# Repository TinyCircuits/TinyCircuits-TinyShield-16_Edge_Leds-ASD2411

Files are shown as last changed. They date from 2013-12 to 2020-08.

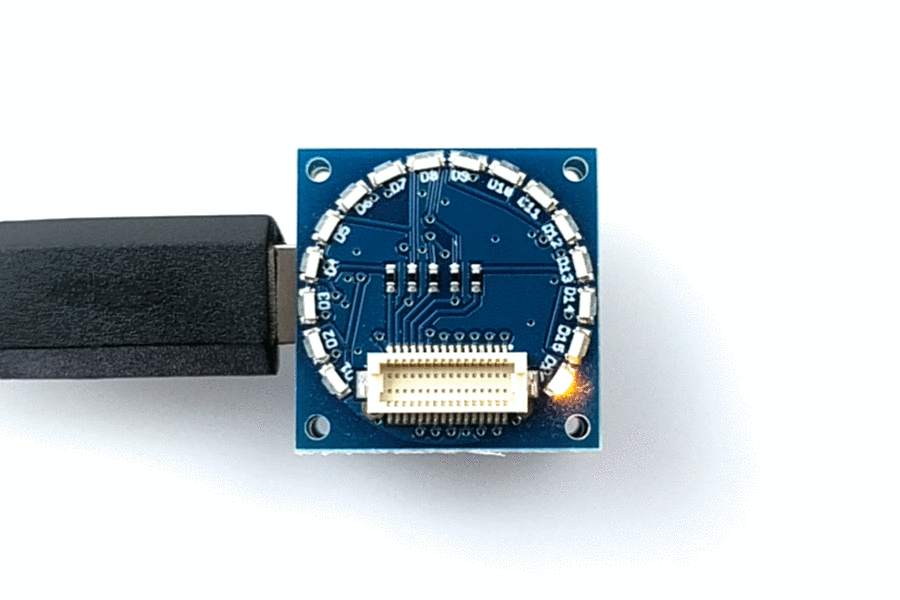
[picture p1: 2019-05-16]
images/ASD2411-R-LG-Tutorial-Animation-01.gif

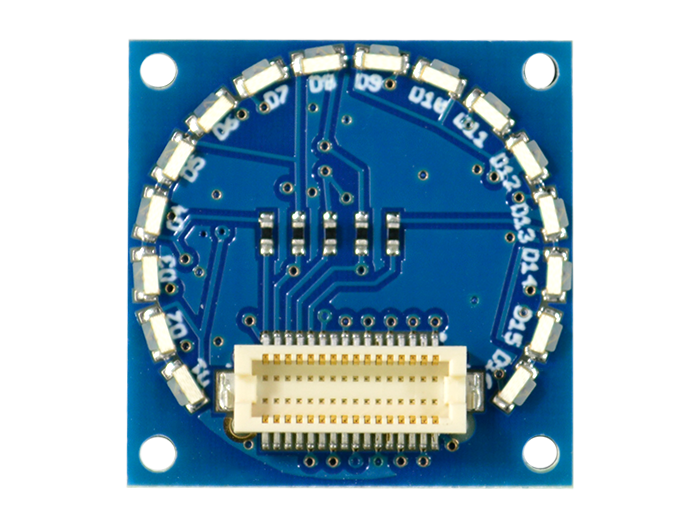
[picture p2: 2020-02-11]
images/ASD2411-R-LG-Tutorial-Image-01.png

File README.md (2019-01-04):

# TinyCircuits TinyShield 16 Edge LEDs
# ASD2411 Rev5

The design files are located under design_files/ for the TinyCircuits ASD2411 Rev 5 PCB.  This is a Tiny shield board (Square Version, 20mm x 20mm, or Circular 20mm diameter) that has a 16 LEDs around the border.

Format is in Cadsoft Eagle format - Eagle version 6.2 was used for the original design.

For more infomation on this, check out the product page at TinyCircuits.com: https://tinycircuits.com/collections/leds-displays/products/16-edge-led-tinyshield

# License:

Design by TinyCircuits.
All design files are released under the Creative Commons Attribution Share-Alike 3.0 License, see the following link for details: http://creativecommons.org/licenses/by-sa/3.0

All text above must be included in any redistribution or derived design

This project uses designs and concepts developed as part of the Arduino project and the LilyPad project.  The TinyCircuits design files themselves (schematics, PCB and libraries) are not directly derived from these works' design files and have been created new, however the concepts and basic architecture behind the TinyDuino and TinyLily products are derived and we thank the hard work of the organizations below for their contributions to open-source hardware:
  
Original Arduino Uno Design by Team Arduino

LilyPad Arduino Design by Leah Buechley and Sparkfun Electronics

Please support the open-source hardware community

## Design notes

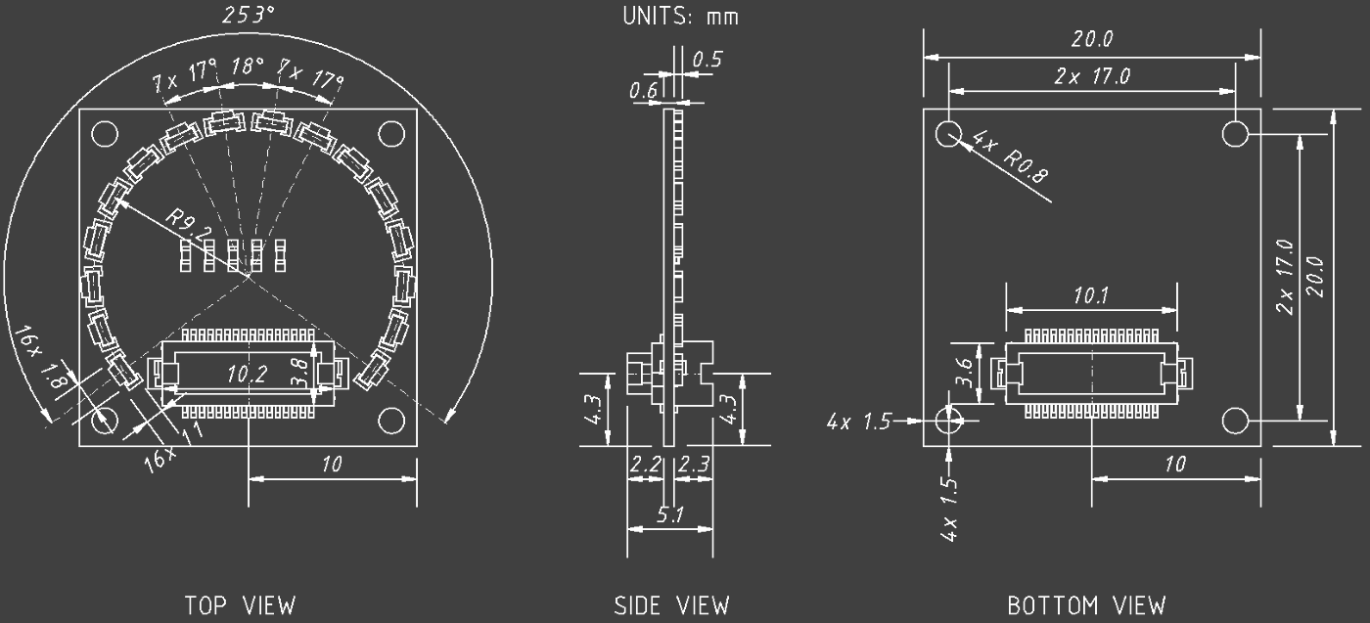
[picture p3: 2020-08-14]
cad/TinyShield_16_EDGE_LEDS_ASD2411-REV5_DETAILED_DRAWING_COMPACT-PNG.png

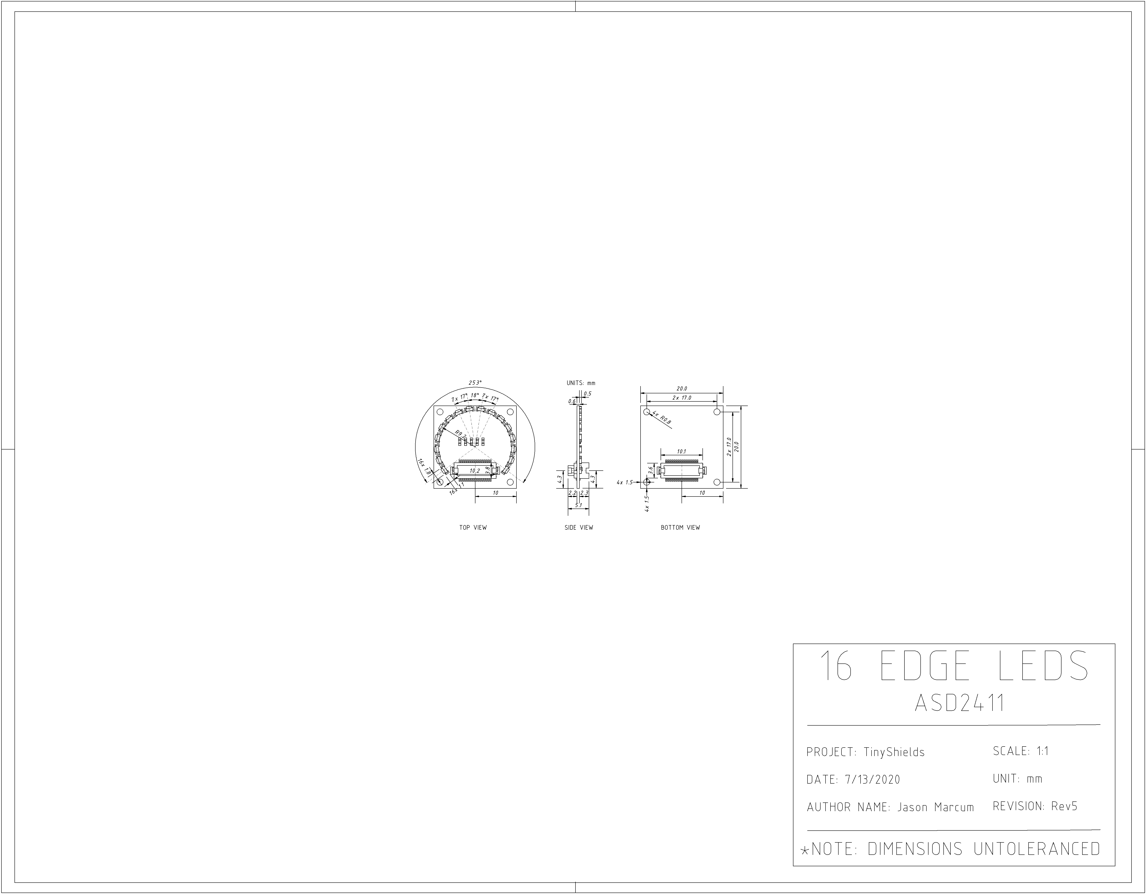
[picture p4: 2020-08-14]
cad/TinyShield_16_EDGE_LEDS_ASD2411_REV5-DETAILED_DRAWING-PNG.png

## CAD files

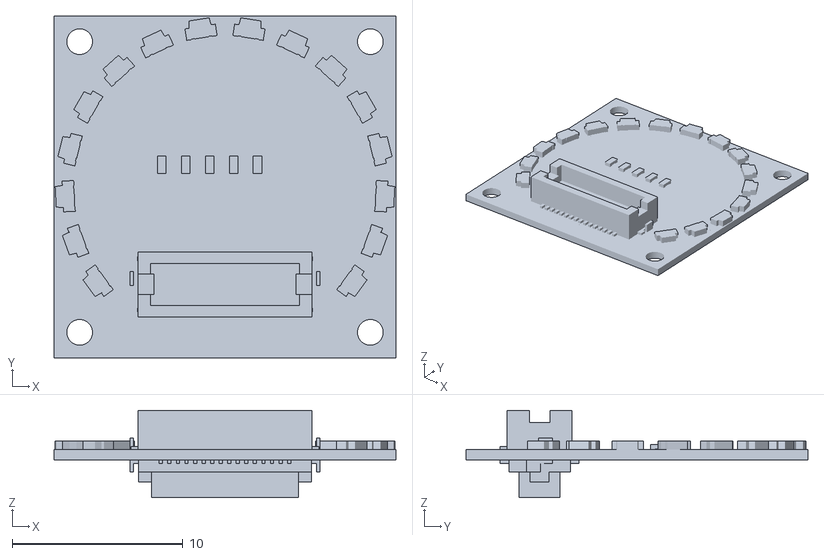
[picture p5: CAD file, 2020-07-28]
cad/TinyShield_16_EDGE_LEDS_ASD2411_REV5-STL.stl
20.0 x 20.0 x 5.10

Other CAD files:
cad/ TinyShield_16_EDGE_LEDS_ASD2411_REV5-DETAILED_DRAWING-DXF.dxf

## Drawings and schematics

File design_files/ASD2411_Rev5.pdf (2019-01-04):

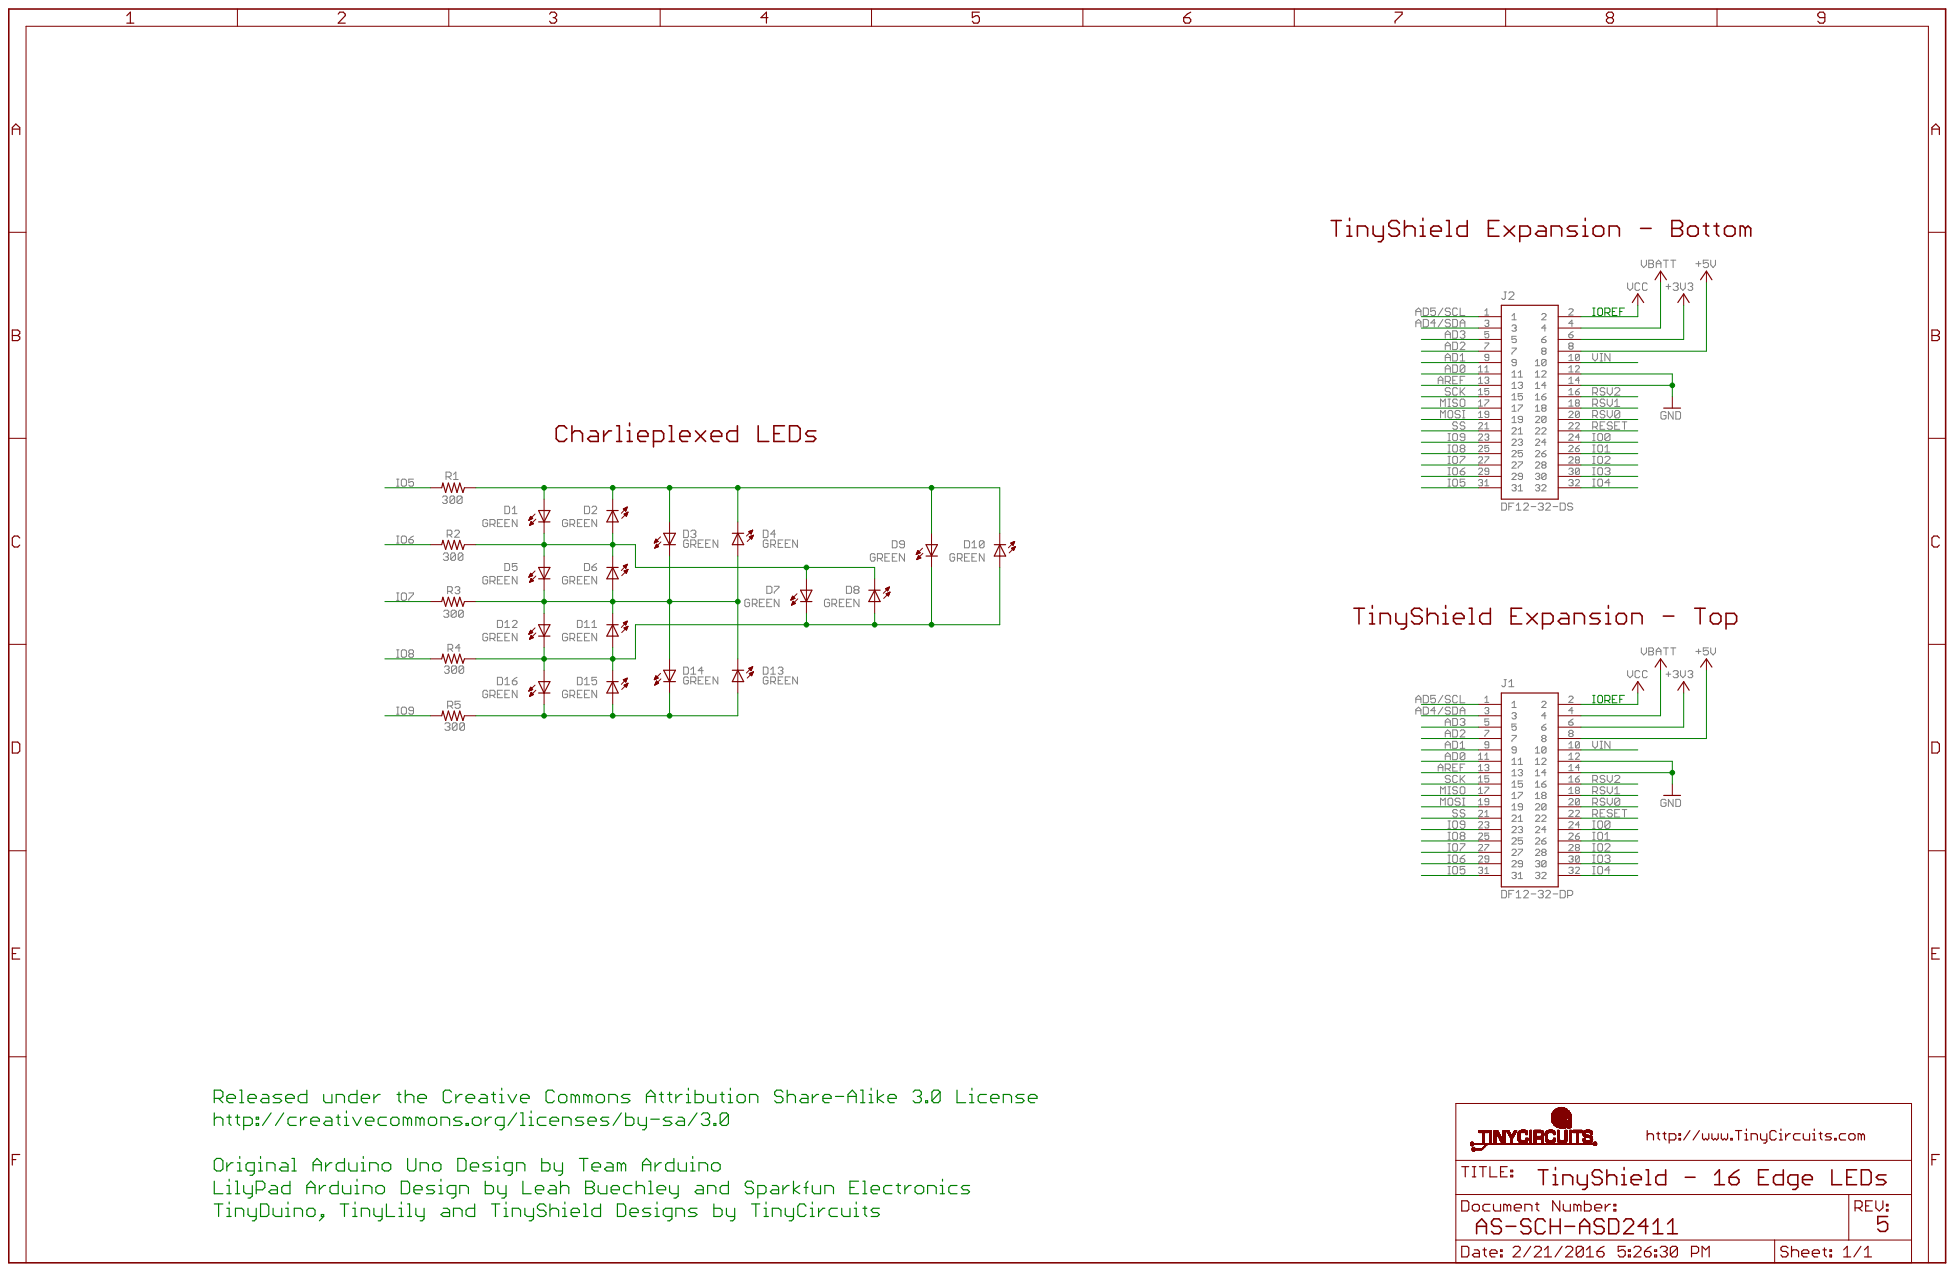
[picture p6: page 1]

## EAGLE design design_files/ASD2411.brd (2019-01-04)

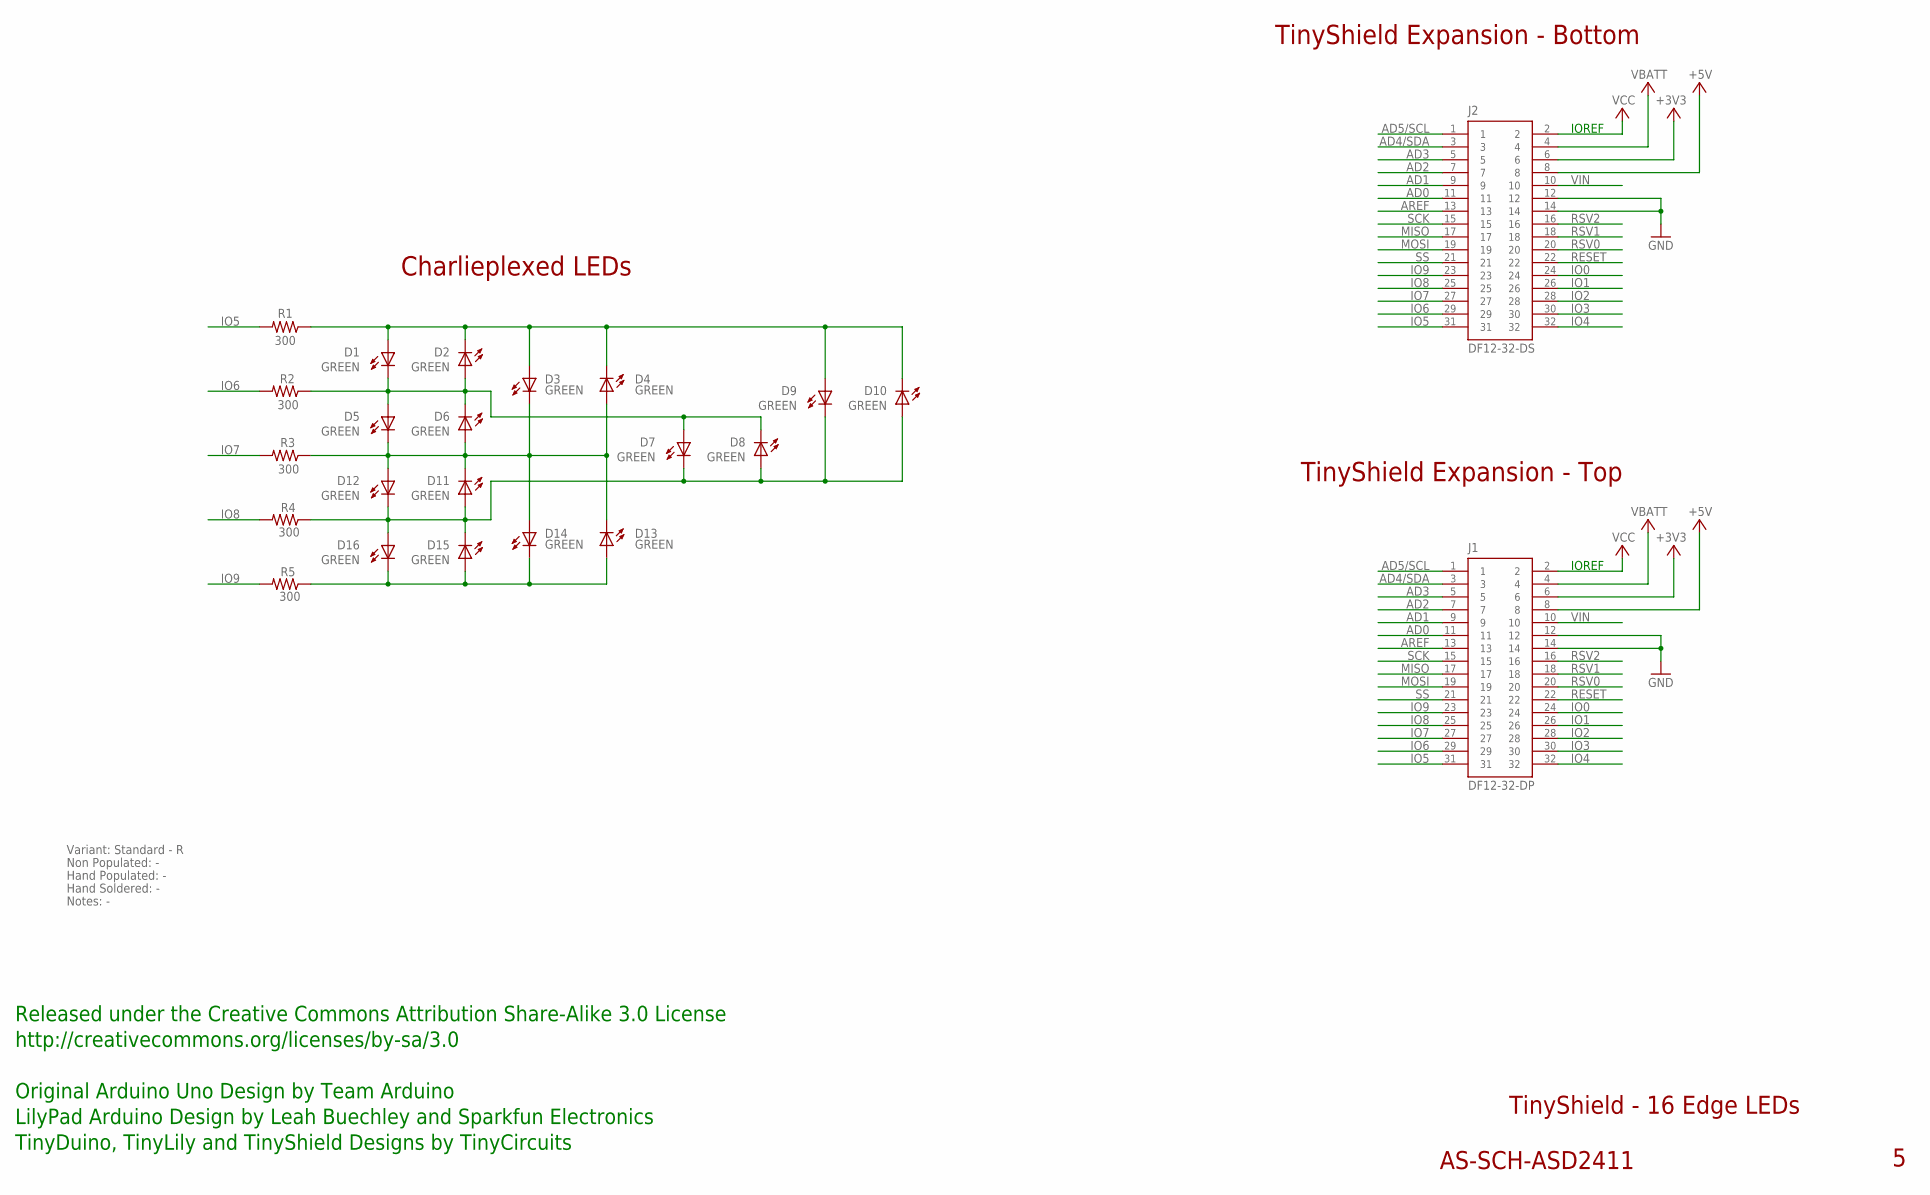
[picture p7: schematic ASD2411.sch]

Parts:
D1, D2, D3, D4, D5, D6, D7, D8, D9, D10, D11, D12, D13, D14, D15, D16: GREEN; LNJ_LED; PARTNO AS-ITM-00011
J1: DF12-32-DP; PARTNO AS-ITM-00015
J2: DF12-32-DS; PARTNO AS-ITM-00012
R1: 300; 0402; PARTNO AS-ITM-00016
R2, R3, R4, R5: 300; 0402

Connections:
+3V3: J1.6, J2.6
+5V: J1.8, J2.8
AD0: J1.11, J2.11
AD1: J1.9, J2.9
AD2: J1.7, J2.7
AD3: J1.5, J2.5
AD4/SDA: J1.3, J2.3
AD5/SCL: J1.1, J2.1
AREF: J1.13, J2.13
GND: J1.12, J1.14, J2.12, J2.14
IO0: J1.24, J2.24
IO1: J1.26, J2.26
IO2: J1.28, J2.28
IO3: J1.30, J2.30
IO4: J1.32, J2.32
IO5: J1.31, J2.31, R1.2
IO6: J1.29, J2.29, R2.2
IO7: J1.27, J2.27, R3.2
IO8: J1.25, J2.25, R4.2
IO9: J1.23, J2.23, R5.2
MISO: J1.17, J2.17
MOSI: J1.19, J2.19
unnamed: D1.C, D2.A, D5.A, D6.C, D7.A, D8.C, R2.1
unnamed: D1.A, D2.C, D3.A, D4.C, D9.A, D10.C, R1.1
unnamed: D3.C, D4.A, D5.C, D6.A, D11.C, D12.A, D13.C, D14.A, R3.1
unnamed: D7.C, D8.A, D9.C, D10.A, D11.A, D12.C, D15.C, D16.A, R4.1
unnamed: D13.A, D14.C, D15.A, D16.C, R5.1
RESET: J1.22, J2.22
RSV0: J1.20, J2.20
RSV1: J1.18, J2.18
RSV2: J1.16, J2.16
SCK: J1.15, J2.15
SS: J1.21, J2.21
VBATT: J1.4, J2.4
VCC: J1.2, J2.2
VIN: J1.10, J2.10

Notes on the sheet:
TinyShield Expansion - Bottom
Charlieplexed LEDs
TinyShield - 16 Edge LEDs
AS-SCH-ASD2411
TinyShield Expansion - Top
IOREF
Released under the Creative Commons Attribution Share-Alike 3.0 License
http://creativecommons.org/licenses/by-sa/3.0
LilyPad Arduino Design by Leah Buechley and Sparkfun Electronics
TinyDuino, TinyLily and TinyShield Designs by TinyCircuits
Original Arduino Uno Design by Team Arduino
Non Populated: -
Hand Populated: -
Hand Soldered: -
Variant: Standard - R
Notes: -

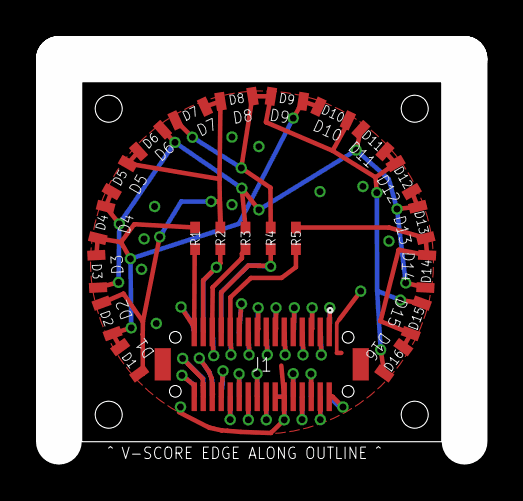
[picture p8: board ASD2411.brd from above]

Board: 2 copper layers, 20.0 x 20.0 mm, 24 parts (1 on the bottom side), 36 nets.

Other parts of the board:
U$1: DOCFIELD-TINYCIRCUITS-PCB

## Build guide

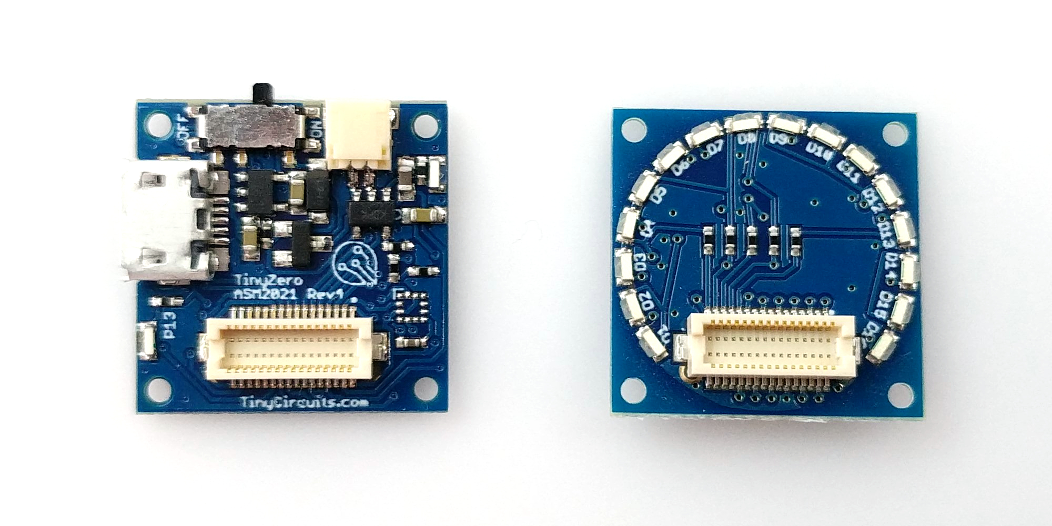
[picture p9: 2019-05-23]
images/ASD2411-R-LG-Tutorial-Image-02.jpg

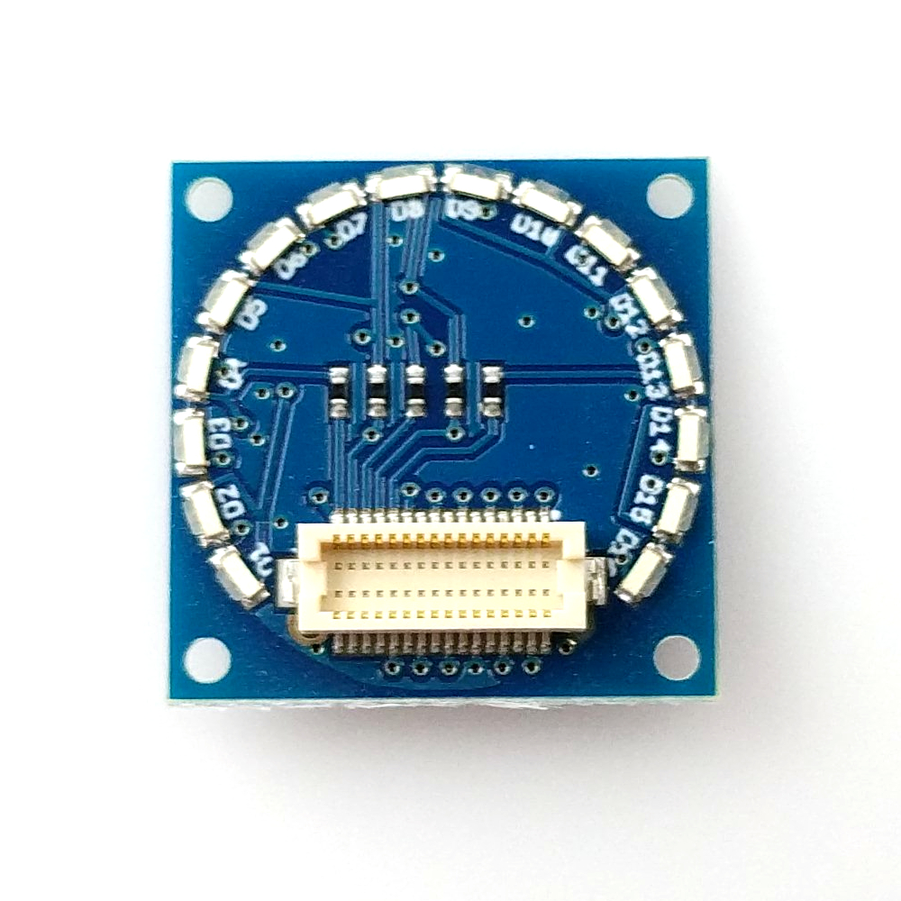
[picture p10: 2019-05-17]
images/ASD2411-R-LG-Tutorial-Image-01.jpg

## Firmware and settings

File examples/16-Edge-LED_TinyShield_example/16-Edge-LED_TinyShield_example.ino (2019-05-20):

/*
  TinyDuino 16 Edge LED TinyShield Example Sketch

  This example turns on one LED at a time,
  from 1 to 16 and then from 16 to 1.
  This example code is in the public domain.

  Written 09 April 2014
  By Ben Rose
  Modified 20 May 2019
  By Hunter Hykes

  https://TinyCircuits.com
*/

void setup()
{
  LedOn(0); //Pass a zero to turn all LEDs off
}

void loop()
{
  for(int i = 1; i < 16 ;i++) {
    LedOn(i);
    delay(20);
  };
  for(int i = 16; i > 1; i--) {
    LedOn(i);
    delay(20);
  };
}

void LedOn(int ledNum)
{
  for(int i = 5; i < 10; i++) {
    pinMode(i, INPUT);
    digitalWrite(i, LOW);
  };
  
  if(ledNum < 1 || ledNum > 16) return;
  
  char highpin[16] = {5,6,5,7,6,7,6,8,5,8,8,7,9,7,9,8};
  char lowpin[16] = {6,5,7,5,7,6,8,6,8,5,7,8,7,9,8,9};
  ledNum--;
  
  digitalWrite(highpin[ledNum], HIGH);
  digitalWrite(lowpin[ledNum], LOW);
  pinMode(highpin[ledNum], OUTPUT);
  pinMode(lowpin[ledNum], OUTPUT);
}

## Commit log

2013-12-24 Updated to Rev 4
    [ASD2411.brd, ASD2411.sch]
2019-01-04 update format and rev
    [ASD2411.brd, ASD2411.sch]
2020-07-28 Add CAD data
    [TinyShield_16_EDGE_LEDS_ASD2411_REV5-DETAILED_DRAWING-DXF.dxf, TinyShield_16_EDGE_LEDS_ASD2411_REV5-STL.stl]
2020-08-14 Update CAD drawing
    [TinyShield_16_EDGE_LEDS_ASD2411_REV5-DETAILED_DRAWING-DXF.dxf]
